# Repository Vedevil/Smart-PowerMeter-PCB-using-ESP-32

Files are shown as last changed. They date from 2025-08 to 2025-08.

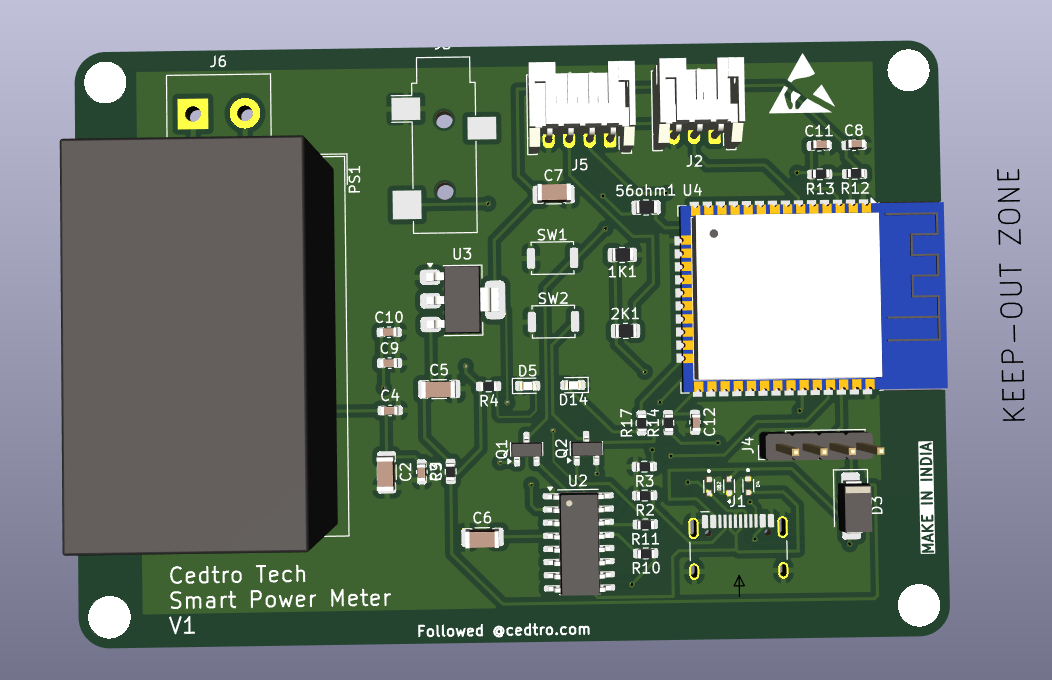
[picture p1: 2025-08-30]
Screenshot 2025-07-06 215419.png

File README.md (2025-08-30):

# Smart-PowerMeter-PCB-using-ESP-32
ESP32-based Smart Power Monitoring PCB with PZEM-004T, ACS712, and SCT013 sensors

⚡ Smart Power Monitor – PCB Design

The Smart Power Monitor PCB is an open-source hardware project built around the ESP32-WROOM-32 microcontroller, designed to measure and monitor voltage, current, power, and energy consumption in real time.

This PCB integrates support for three widely used energy measurement modules:

PZEM-004T – For accurate voltage, power, and energy measurement.

ACS712 – A Hall-effect current sensor for low-current measurements.

SCT013 – A non-invasive current clamp for higher AC load monitoring.

The design is tailored for IoT applications, where energy usage data can be logged, analyzed, and transmitted wirelessly. With the ESP32 at its core, this PCB is capable of connecting to MQTT brokers, cloud dashboards, or local monitoring systems, enabling use in smart homes, research labs, and industrial automation setups.

✨ Key Features

ESP32-WROOM-32 Controller – WiFi + Bluetooth connectivity out of the box.

Multi-Sensor Support – Compatible with PZEM-004T, ACS712, and SCT013.

Compact PCB Form Factor – Optimized 2-layer PCB for low-cost fabrication.

Open Source – All schematics, PCB files, and Gerbers are free to use.

IoT Ready – Designed for integration with MQTT dashboards, Home Assistant, or custom mobile apps.

Educational Value – Perfect for learning PCB design, IoT systems, and power electronics.

📐 Hardware Overview

Power Supply: 5V input via barrel jack or header.

Connectivity: UART/I²C headers for sensor interfacing.

Measurement Range:

Voltage: 80–260V AC (via PZEM-004T)

Current: 0–20A (via ACS712)

Current: up to 100A (via SCT013 clamp)

PCB Layers: 2 (optimized for easy manufacturing).

Software Support: Arduino IDE / PlatformIO with ESP32 libraries.

🛠️ Applications

Smart Home Energy Monitoring (track appliances, reduce consumption).

Industrial Load Monitoring (real-time analysis of machines and equipment).

IoT Dashboards (publish data to the cloud using MQTT/HTTP).

Academic & Research Projects (power electronics, embedded systems).

Low-cost alternative to commercial energy meters.

📦 Repository Contents

/hardware/ – KiCad schematic, PCB layout, Gerber files, BOM.

/docs/ – PCB renders, diagrams, and usage notes.

LICENSE – MIT License for free usage and modifications.

README.md – Documentation and project overview.

🔧 How to Get Started

Clone the repository:

git clone https://github.com/<your-username>/SmartPowerMonitor-PCB.git

Open the .sch and .kicad_pcb files in KiCad (v6+ recommended).

Export Gerbers using KiCad’s plot function.

Upload Gerbers (SmartPowerMonitor-Gerbers.zip) to PCB manufacturers (JLCPCB, PCBWay, etc.).

Order components from the BOM and assemble.

Flash ESP32 with your firmware to start monitoring energy.

📊 Example Workflow

Connect AC load to sensors (e.g., lamp, motor).

ESP32 reads measurements from PZEM-004T, ACS712, or SCT013.

Data is displayed via Serial Monitor or sent over WiFi.

MQTT broker or IoT dashboard logs the data.

User tracks real-time and historical energy consumption.

📜 License

This project is licensed under the MIT License – you are free to use, modify, and distribute, provided proper credit is given.
Schematic 


Layout


3D View


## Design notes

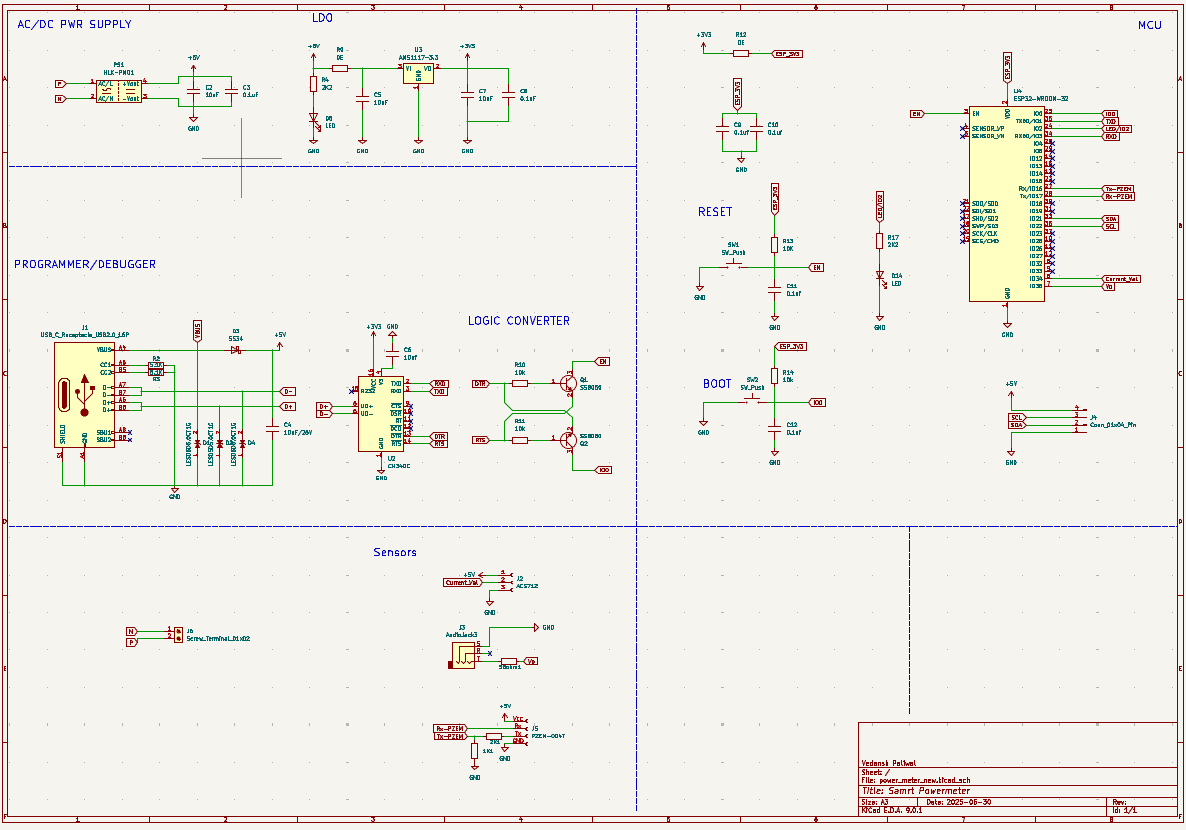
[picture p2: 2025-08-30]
image.png

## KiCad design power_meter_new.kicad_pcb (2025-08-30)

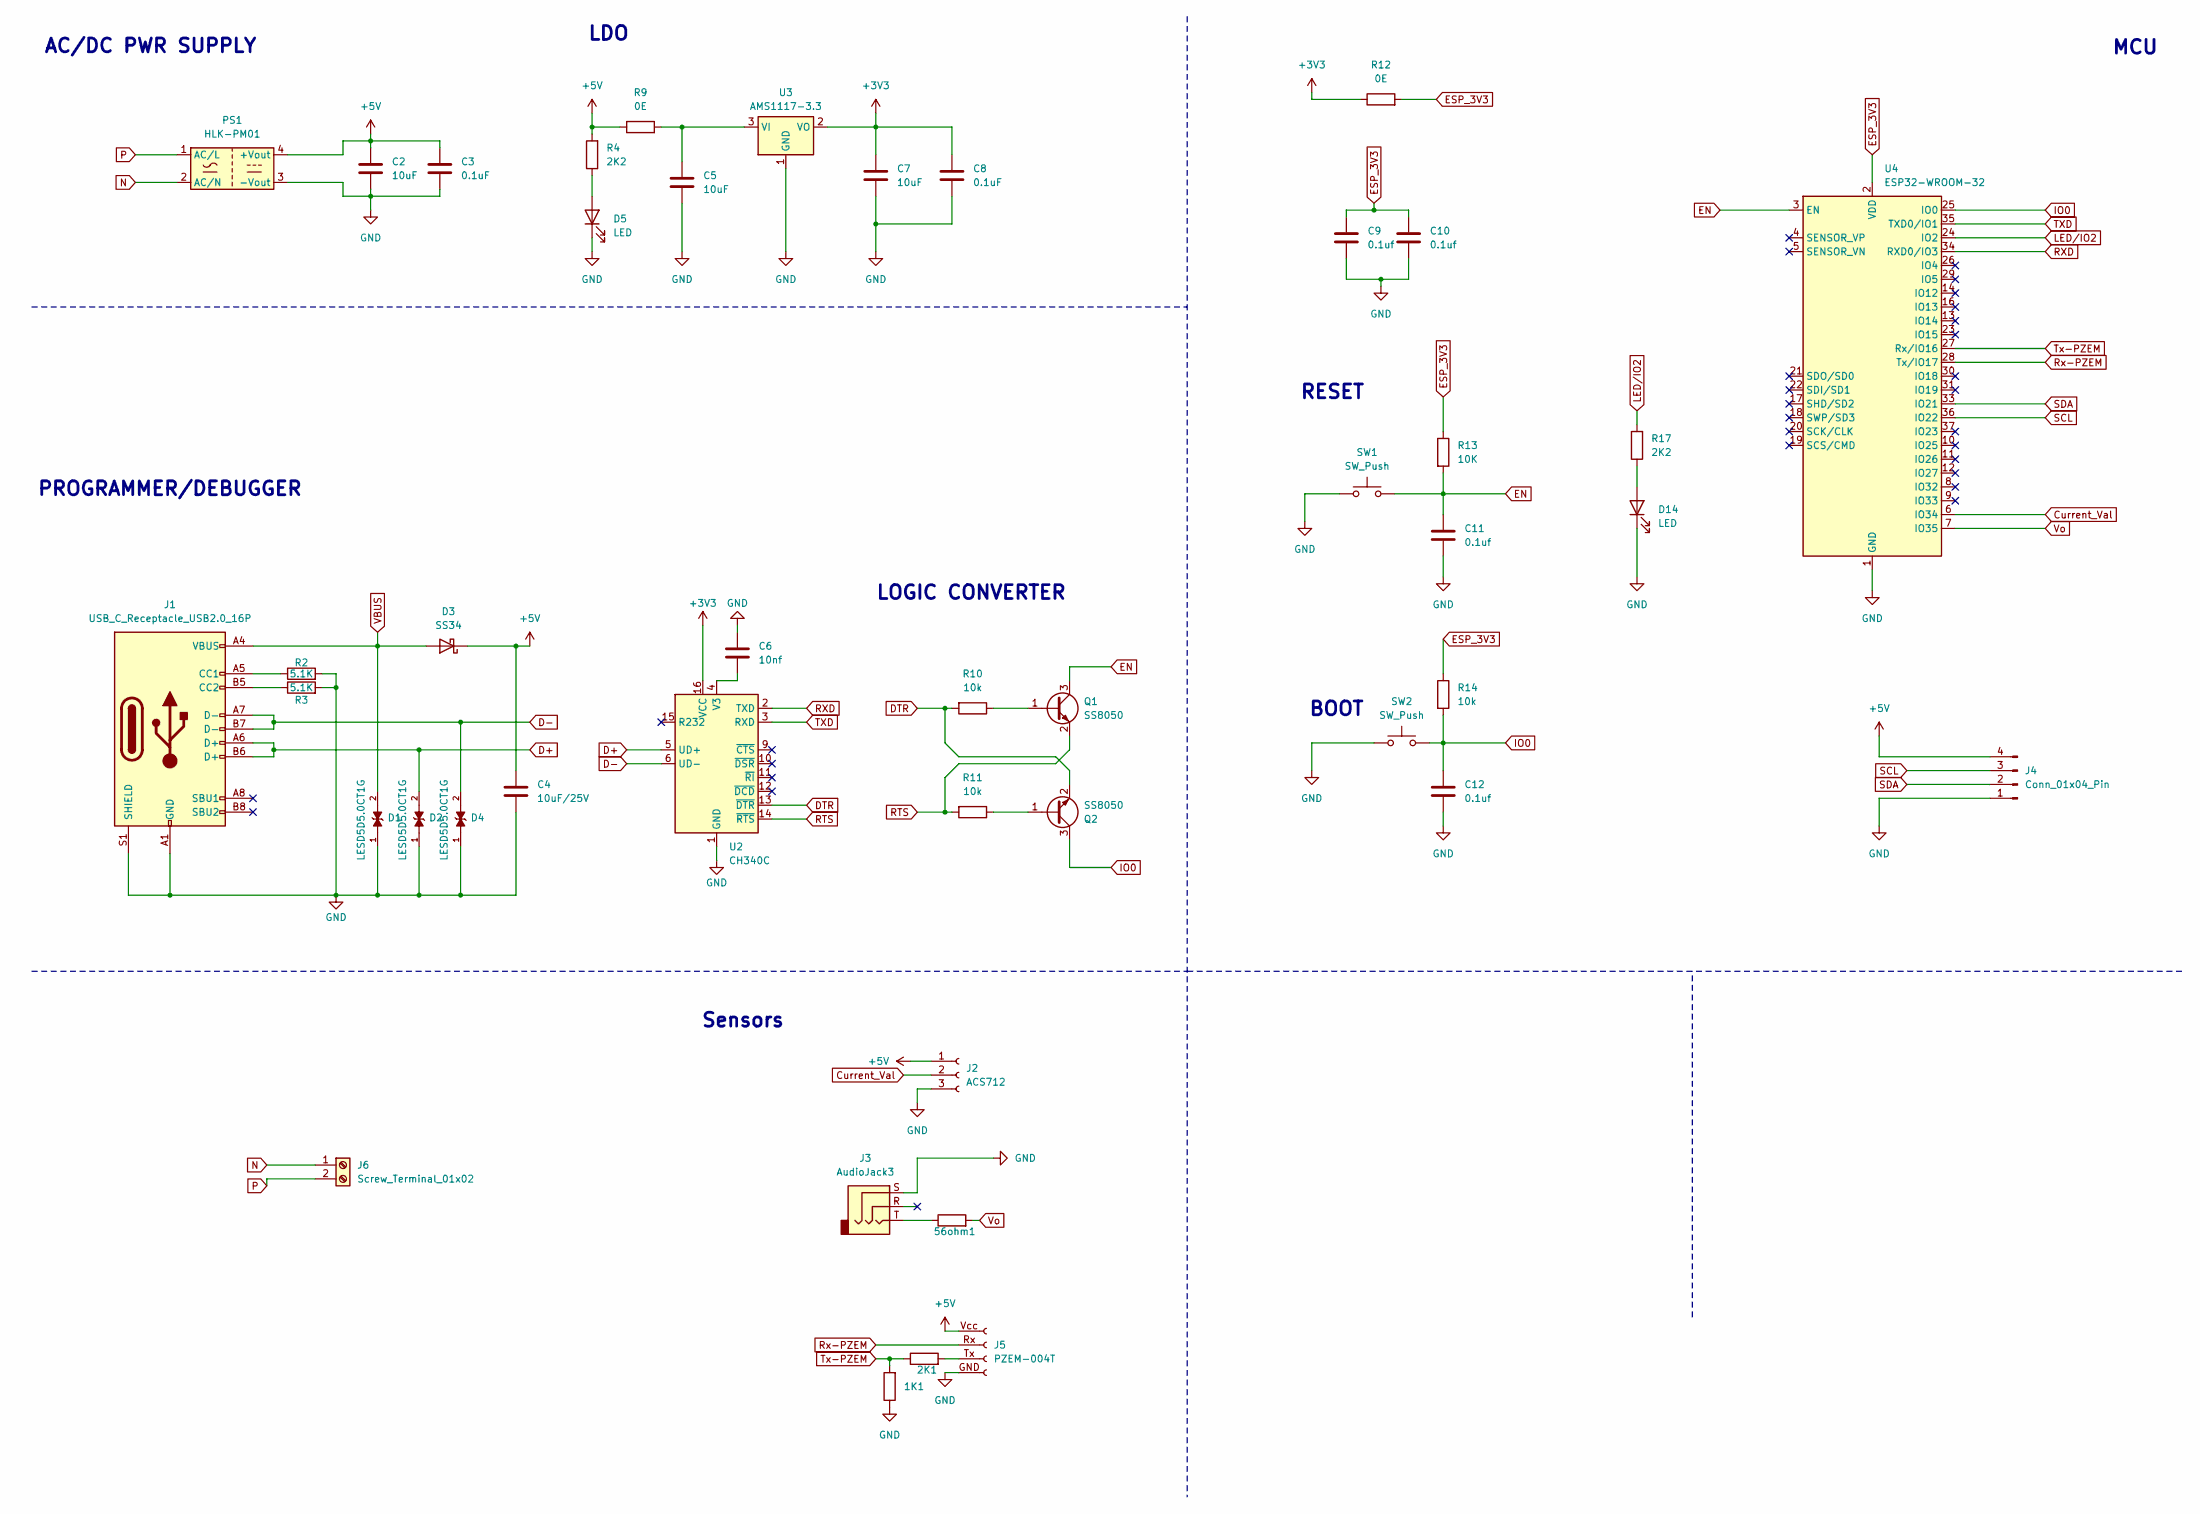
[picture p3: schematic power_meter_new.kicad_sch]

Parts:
1K1: 1K; R_0805_2012Metric
2K1, 56ohm1: 56; R_0805_2012Metric
C2, C5, C7: 10uF; C_1206_3216Metric
C3, C8: 0.1uF; C_0603_1608Metric
C4: 10uF/25V; C_0603_1608Metric
C6: 10nf; C_1206_3216Metric
C9, C10, C11, C12: 0.1uf; C_0603_1608Metric
D1, D2, D4: LESD5D5.0CT1G; TVS_LESD5D5.0CT1G; PARTREV O
D3: SS34; D_SMA
D5, D14: LED; LED_0603_1608Metric
J1: USB_C_Receptacle_USB2.0_16P; USB_C_Receptacle_HCTL_HC-TYPE-C-16P-01A
J2: ACS712; JST_PH_S3B-PH-K_1x03_P2.00mm_Horizontal
J3: AudioJack3; Jack_3.5mm_CUI_SJ-3523-SMT_Horizontal
J4: Conn_01x04_Pin; PinHeader_1x04_P2.54mm_Vertical
J5: PZEM-004T; JST_PH_B4B-PH-K_1x04_P2.00mm_Vertical
J6: Screw_Terminal_01x02; TerminalBlock_bornier-2_P5.08mm
PS1: HLK-PM01; Converter_ACDC_Hi-Link_HLK-PMxx
Q1, Q2: SS8050; SOT-23
R2, R3: 5.1K; R_0603_1608Metric
R4, R17: 2K2; R_0603_1608Metric
R9, R12: 0E; R_0603_1608Metric
R10, R11, R14: 10k; R_0603_1608Metric
R13: 10K; R_0603_1608Metric
SW1, SW2: SW_Push; SW_Push_SPST_NO_Alps_SKRK
U2: CH340C; SOIC-16_3.9x9.9mm_P1.27mm
U3: AMS1117-3.3; SOT-223-3_TabPin2
U4: ESP32-WROOM-32

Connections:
+3V3: C7.1, C8.1, R12.1, U2.16 (VCC), U3.2 (VO)
+5V: C2.1, C3.1, C4.1, D3.1 (K), J2.1, J4.4, J5.Vcc (Pin_1), PS1.4 (+Vout), R4.2, R9.1
Current_Val: J2.2, U4.6 (IO34)
D+: D2.2, J1.A6 (D+), J1.B6 (D+), U2.5 (UD+)
D-: D4.2, J1.A7 (D-), J1.B7 (D-), U2.6 (UD-)
DTR: Q2.2 (E), R10.2, U2.13 (~DTR)
EN: C11.1, Q1.3 (C), R13.2, SW1.2, U4.3 (EN)
ESP_3V3: C9.1, C10.1, R12.2, R13.1, R14.1, U4.2 (VDD)
GND: 1K1.1, C2.2, C3.2, C4.2, C5.2, C6.1, C7.2, C8.2, C9.2, C10.2, C11.2, C12.2, D1.1, D2.1, D4.1, D5.1 (K), D14.1 (K), J1.A1 (GND), J1.A12 (GND), J1.B1 (GND), J1.B12 (GND), J1.S1 (SHIELD), J2.3, J3.S, J4.1, J5.GND (Pin_4), PS1.3 (-Vout), R2.2, R3.2, SW1.1, SW2.1, U2.1 (GND), U3.1 (GND), U4.1 (GND), U4.15 (GND), U4.38 (GND), U4.39 (GND)
IO0: C12.1, Q2.3 (C), R14.2, SW2.2, U4.25 (IO0)
LED/IO2: R17.2, U4.24 (IO2)
N: J6.1, PS1.2 (AC/N)
unnamed: 56ohm1.1, J3.T
unnamed: D5.2 (A), R4.1
unnamed: D14.2 (A), R17.1
unnamed: J1.A5 (CC1), R2.1
unnamed: J1.B5 (CC2), R3.1
unnamed: 2K1.2, J5.Tx (Pin_3)
unnamed: Q1.1 (B), R10.1
unnamed: Q2.1 (B), R11.1
unnamed: C6.2, U2.4 (V3)
unnamed: C5.1, R9.2, U3.3 (VI)
P: J6.2, PS1.1 (AC/L)
RTS: Q1.2 (E), R11.2, U2.14 (~RTS)
RXD: U2.2 (TXD), U4.34 (RXD0/IO3)
Rx-PZEM: J5.Rx (Pin_2), U4.28 (Tx/IO17)
SCL: J4.3, U4.36 (IO22)
SDA: J4.2, U4.33 (IO21)
TXD: U2.3 (RXD), U4.35 (TXD0/IO1)
Tx-PZEM: 1K1.2, 2K1.1, U4.27 (Rx/IO16)
VBUS: D1.2, D3.2 (A), J1.A4 (VBUS), J1.A9 (VBUS), J1.B4 (VBUS), J1.B9 (VBUS)
Vo: 56ohm1.2, U4.7 (IO35)

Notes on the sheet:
MCU
LDO
LOGIC CONVERTER
AC/DC PWR SUPPLY
RESET
Sensors
BOOT
PROGRAMMER/DEBUGGER

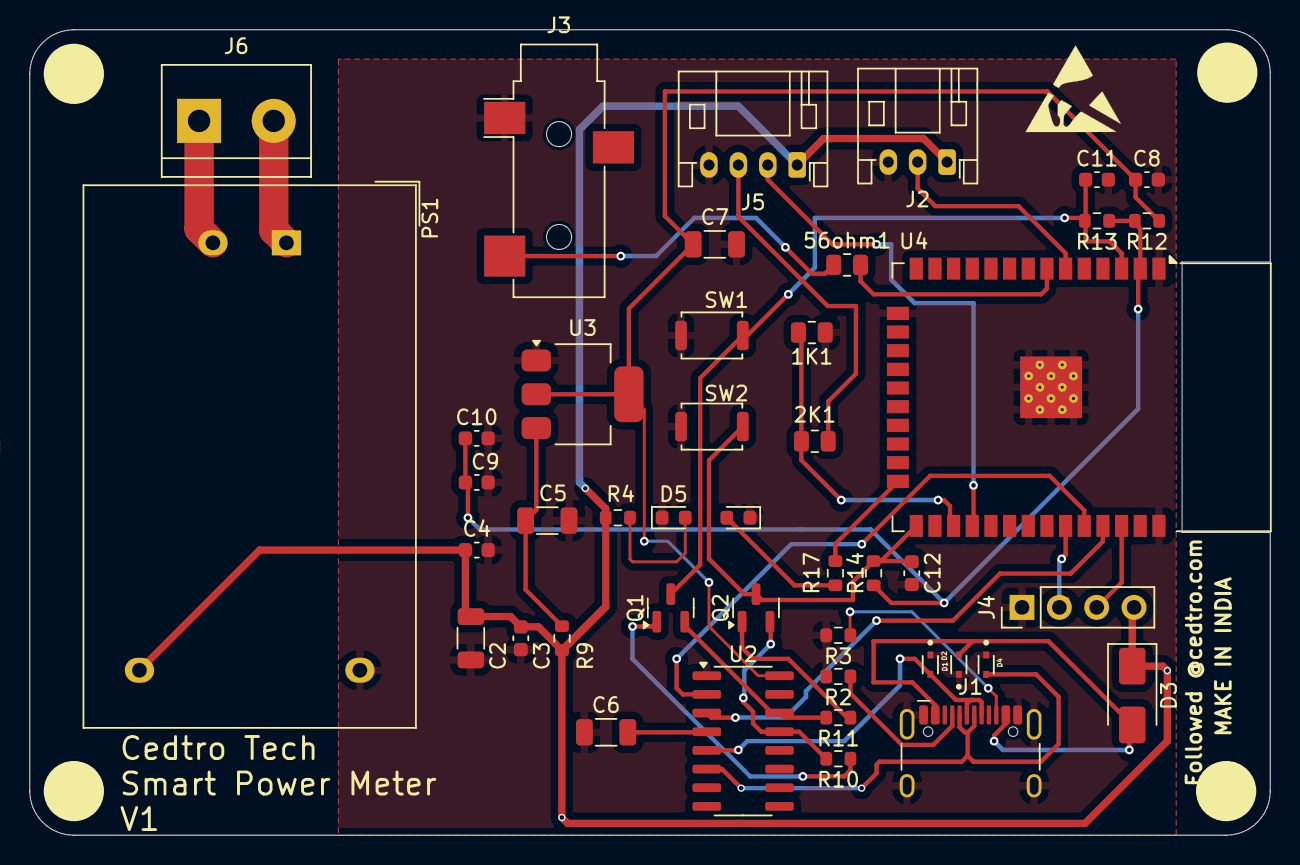
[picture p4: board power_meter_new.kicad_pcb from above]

Board: 2 copper layers, 84.4 x 54.8 mm, 44 parts (0 on the bottom side), 32 nets.
